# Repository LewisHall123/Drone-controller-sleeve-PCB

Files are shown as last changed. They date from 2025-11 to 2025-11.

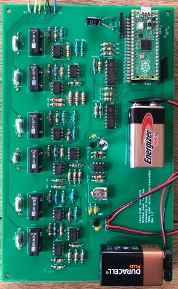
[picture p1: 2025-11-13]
TENG_input_PCB.jpg

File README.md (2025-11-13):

# Drone-controller-sleeve-PCB
A circuit designed to send commands to a drone that it controls. The inputs to the circuit that determine the commands come from six separate tribo-electric nanogenerators (TENG). The materials used for the TENG were aluminium foil and fluorinated ethylene propylene (FEP). The aluminium foil was arranged as six squares that sat on a sleeve that was secured to the users forearm. The aluminium squares were connected to electrodes that were inputs to the circuit. A glove was used with FEP material on the fingertips, and so when the user touched the aluminium squares on the sleeve, a voltage was created in the aluminium squares.
The six aluminium squares were controlls that were responsible for increasing or decreasing the values of roll, pitch, and yaw of the drone.
A Raspberry Pi Pico was used to determine the exact messages that could be sent to the HC-12 transceiver that would transmitt the commands to the drone.

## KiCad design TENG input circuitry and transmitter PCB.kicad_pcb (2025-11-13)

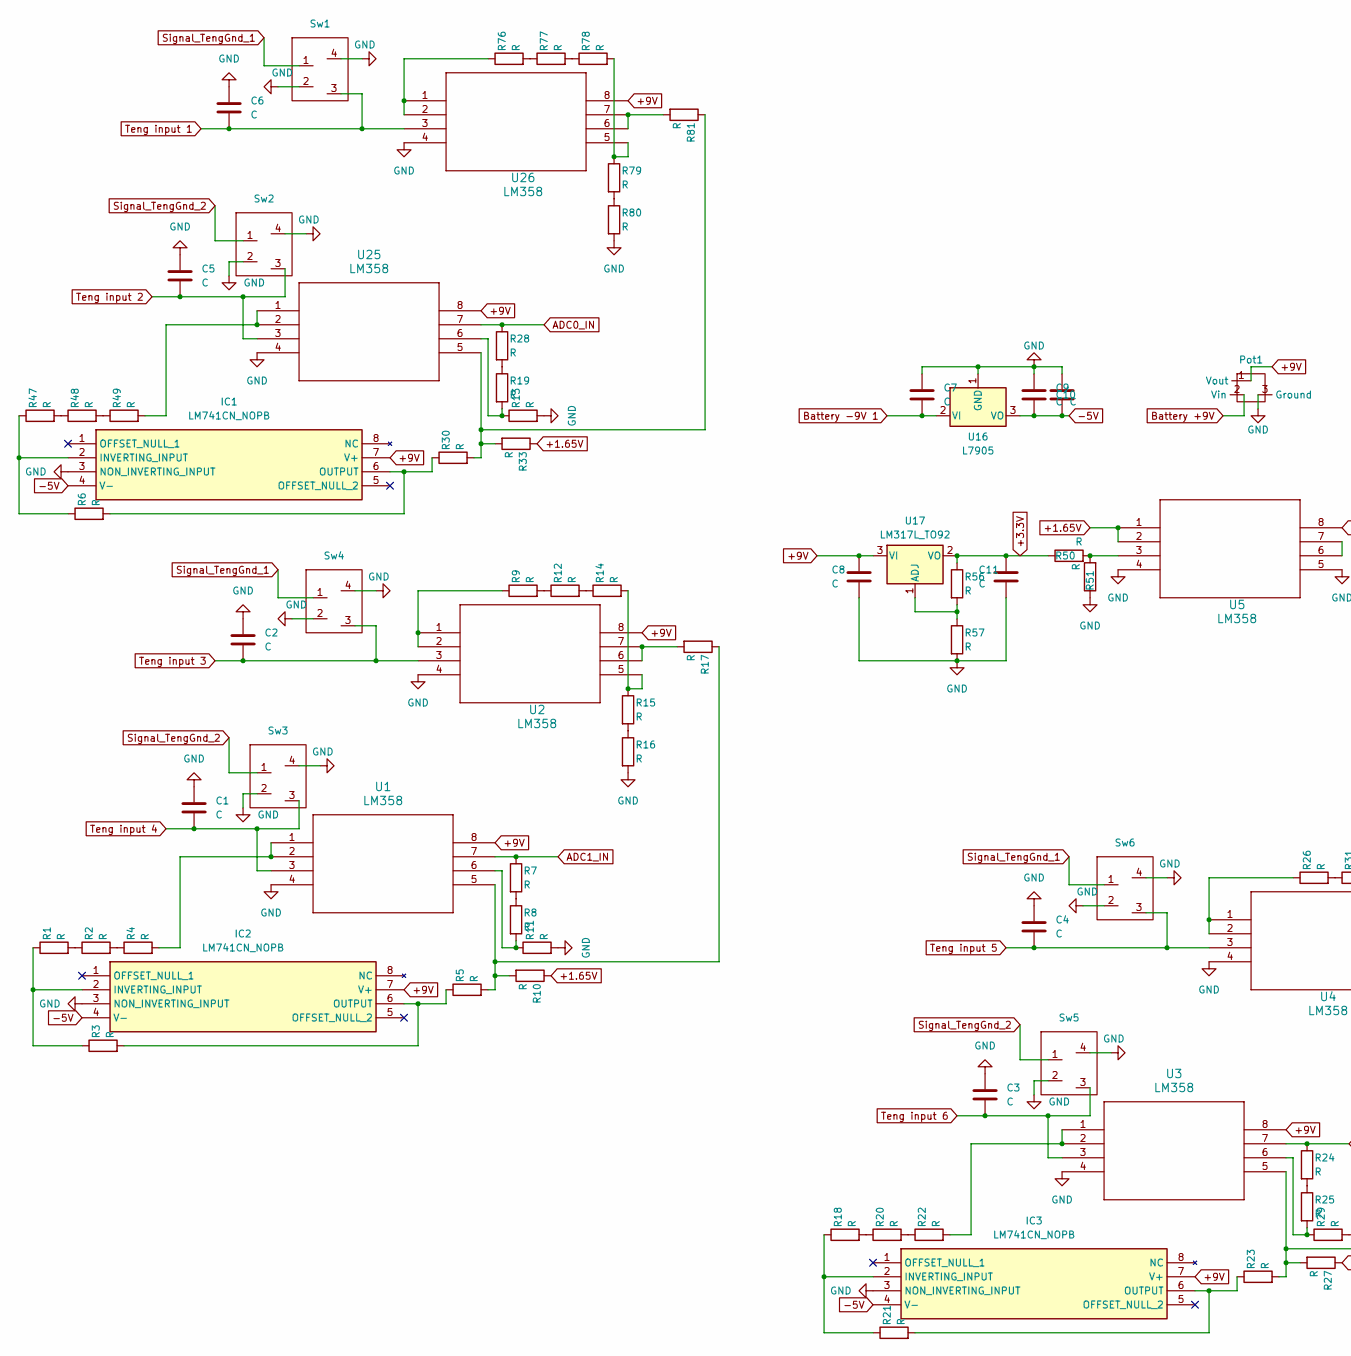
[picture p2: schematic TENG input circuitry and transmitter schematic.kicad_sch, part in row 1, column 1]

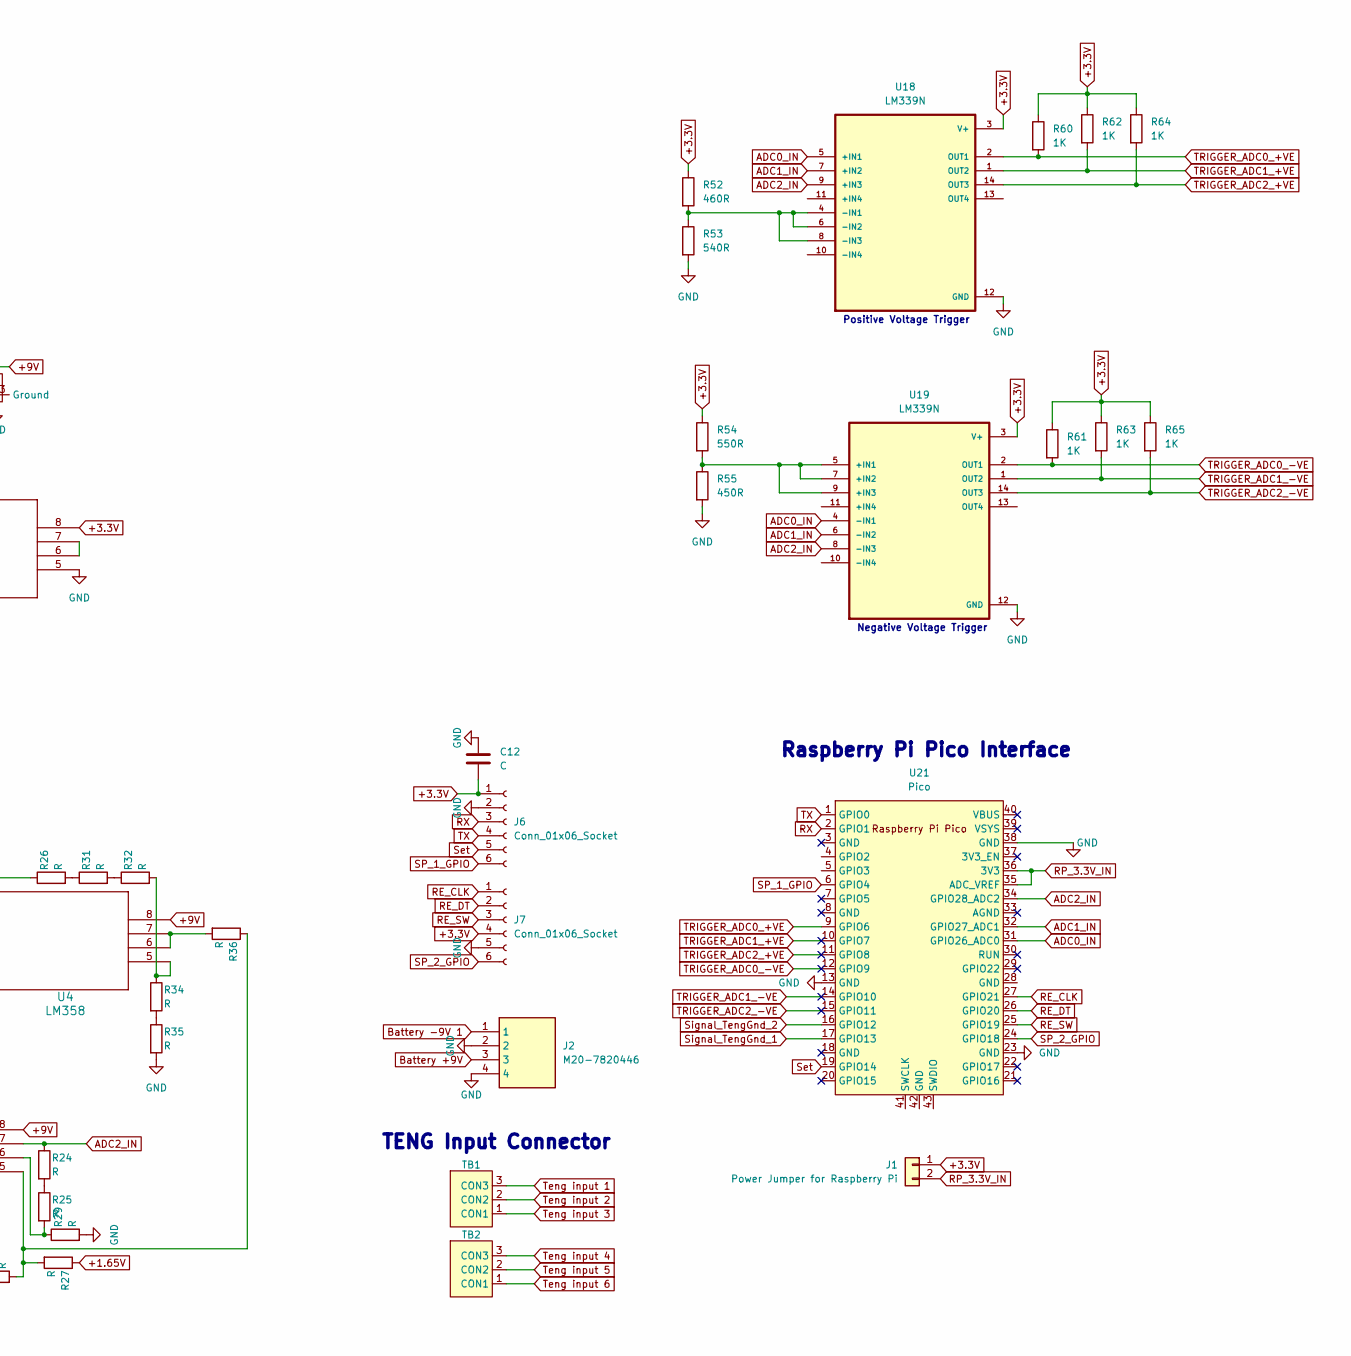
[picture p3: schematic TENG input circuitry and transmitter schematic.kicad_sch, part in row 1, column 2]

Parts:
C1, C2, C3, C4, C5, C6: C; CP_Axial_L10.0mm_D6.0mm_P15.00mm_Horizontal
C7, C9, C10, C11, C12: C; C_Axial_L3.8mm_D2.6mm_P7.50mm_Horizontal
C8: C; CP_Radial_D8.0mm_P5.00mm
IC1, IC2, IC3: LM741CN_NOPB; DIP794W53P254L959H508Q8N; Mouser Part Number 926-LM741CN/NOPB
J1: Power Jumper for Raspberry Pi; PinHeader_1x02_P2.54mm_Vertical
J2: M20-7820446; RHDR4W70P0X254_1X4_1056X250X865P; Mouser Part Number 855-M20-7820446
J6, J7: Conn_01x06_Socket; PinSocket_1x06_P2.54mm_Vertical
Pot1: 3359V-A05
R1, R2, R3, R4, R5, R6, R7, R8, R9, R10, R11, R12, R13, R14, R15, R16, R17, R18, R19, R20, R21, R22, R23, R24, R25, R26, R27, R28, R29, R30, R31, R32, R33, R34, R35, R36, R47, R48, R49, R50, R51, R56, R57, R76, R77, R78, R79, R80, R81: R; R_Axial_DIN0207_L6.3mm_D2.5mm_P10.16mm_Horizontal
R52: 460R; R_Axial_DIN0207_L6.3mm_D2.5mm_P10.16mm_Horizontal
R53: 540R; R_Axial_DIN0207_L6.3mm_D2.5mm_P10.16mm_Horizontal
R54: 550R; R_Axial_DIN0207_L6.3mm_D2.5mm_P10.16mm_Horizontal
R55: 450R; R_Axial_DIN0207_L6.3mm_D2.5mm_P10.16mm_Horizontal
R60, R61, R62, R63, R64, R65: 1K; R_Axial_DIN0207_L6.3mm_D2.5mm_P10.16mm_Horizontal
Sw1, Sw2, Sw3, Sw4, Sw5, Sw6: RS 291-9675
TB1, TB2: CTB30513BK
U1, U2, U3, U4, U5, U25, U26: LM358; DIP8_300
U16: L7905; LM336BLPE325
U17: LM317L_TO92; LM336BLPE325
U18, U19: LM339N; LM339
U21: Pico; New Pico

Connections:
+1.65V: R10.1, R27.1, R33.1, U5.1, U5.2
+3.3V: C11.1, C12.2, J1.1, J6.1, J7.4, R50.1, R52.1, R54.1, R56.1, R60.1, R61.1, R62.1, R63.1, R64.1, R65.1, U5.8, U17.2 (VO), U18.3 (V+), U19.3 (V+)
+9V: C8.1, IC1.7 (V+), IC2.7 (V+), IC3.7 (V+), Pot1.1 (Vout), U1.8, U2.8, U3.8, U4.8, U17.3 (VI), U25.8, U26.8
-5V: C9.2, C10.2, IC1.4 (V-), IC2.4 (V-), IC3.4 (V-), U16.3 (VO)
ADC0_IN: R28.1, U18.5 (+IN1), U19.4 (-IN1), U21.31 (GPIO26_ADC0), U25.7
ADC1_IN: R7.1, U1.7, U18.7 (+IN2), U19.6 (-IN2), U21.32 (GPIO27_ADC1)
ADC2_IN: R24.1, U3.7, U18.9 (+IN3), U19.8 (-IN3), U21.34 (GPIO28_ADC2)
Battery +9V: J2.3, Pot1.2 (Vin)
Battery -9V 1: C7.2, J2.1, U16.2 (VI)
GND: C1.1, C2.1, C3.1, C4.1, C5.1, C6.1, C7.1, C8.2, C9.1, C10.1, C11.2, C12.1, IC1.3 (NON_INVERTING_INPUT), IC2.3 (NON_INVERTING_INPUT), IC3.3 (NON_INVERTING_INPUT), J2.2, J2.4, J6.2, J7.5, Pot1.3 (Ground), R11.2, R13.2, R16.2, R29.2, R35.2, R51.1, R53.2, R55.2, R57.2, R80.2, Sw1.2, Sw1.4, Sw2.2, Sw2.4, Sw3.2, Sw3.4, Sw4.2, Sw4.4, Sw5.2, Sw5.4, Sw6.2, Sw6.4, U1.4, U2.4, U3.4, U4.4, U5.4, U5.5, U16.1 (GND), U18.12 (GND), U19.12 (GND), U21.13 (GND), U21.23 (GND), U21.38 (GND), U25.4, U26.4
unnamed: IC1.2 (INVERTING_INPUT), R6.1, R47.1
unnamed: IC1.6 (OUTPUT), R6.2, R30.1
unnamed: IC2.2 (INVERTING_INPUT), R1.1, R3.1
unnamed: IC2.6 (OUTPUT), R3.2, R5.1
unnamed: IC3.2 (INVERTING_INPUT), R18.1, R21.1
unnamed: IC3.6 (OUTPUT), R21.2, R23.1
unnamed: R1.2, R2.1
unnamed: R2.2, R4.1
unnamed: R4.2, U1.1, U1.2
unnamed: R7.2, R8.1
unnamed: R9.1, U2.1, U2.2
unnamed: R5.2, R10.2, R17.1, U1.5
unnamed: R8.2, R11.1, U1.6
unnamed: R9.2, R12.1
unnamed: R12.2, R14.1
unnamed: R13.1, R19.2, U25.6
unnamed: R14.2, R15.1, U2.5
unnamed: R15.2, R16.1
unnamed: R17.2, U2.6, U2.7
unnamed: R18.2, R20.1
unnamed: R19.1, R28.2
unnamed: R20.2, R22.1
unnamed: R22.2, U3.1, U3.2
unnamed: R23.2, R27.2, R36.1, U3.5
unnamed: R24.2, R25.1
unnamed: R25.2, R29.1, U3.6
unnamed: R26.1, U4.1, U4.2
unnamed: R26.2, R31.1
unnamed: R30.2, R33.2, R81.1, U25.5
unnamed: R31.2, R32.1
unnamed: R32.2, R34.1, U4.5
unnamed: R34.2, R35.1
unnamed: R36.2, U4.6, U4.7
unnamed: R47.2, R48.1
unnamed: R48.2, R49.1
unnamed: R49.2, U25.1, U25.2
unnamed: R50.2, R51.2, U5.3
unnamed: R76.1, U26.1, U26.2
unnamed: R76.2, R77.1
unnamed: R77.2, R78.1
unnamed: R78.2, R79.1, U26.5
unnamed: R79.2, R80.1
unnamed: R81.2, U26.6, U26.7
unnamed: U5.6, U5.7
unnamed: R56.2, R57.1, U17.1 (ADJ)
unnamed: R52.2, R53.1, U18.4 (-IN1), U18.6 (-IN2), U18.8 (-IN3)
unnamed: R54.2, R55.1, U19.5 (+IN1), U19.7 (+IN2), U19.9 (+IN3)
RE_CLK: J7.1, U21.27 (GPIO21)
RE_DT: J7.2, U21.26 (GPIO20)
RE_SW: J7.3, U21.25 (GPIO19)
RP_3.3V_IN: J1.2, U21.35 (ADC_VREF), U21.36 (3V3)
RX: J6.3, U21.2 (GPIO1)
SP_1_GPIO: J6.6, U21.6 (GPIO4)
SP_2_GPIO: J7.6, U21.24 (GPIO18)
Set: J6.5, U21.19 (GPIO14)
Signal_TengGnd_1: Sw1.1, Sw4.1, Sw6.1, U21.17 (GPIO13)
Signal_TengGnd_2: Sw2.1, Sw3.1, Sw5.1, U21.16 (GPIO12)
TRIGGER_ADC0_+VE: R60.2, U18.2 (OUT1), U21.9 (GPIO6)
TRIGGER_ADC0_-VE: R61.2, U19.2 (OUT1), U21.12 (GPIO9)
TRIGGER_ADC1_+VE: R62.2, U18.1 (OUT2), U21.10 (GPIO7)
TRIGGER_ADC1_-VE: R63.2, U19.1 (OUT2), U21.14 (GPIO10)
TRIGGER_ADC2_+VE: R64.2, U18.14 (OUT3), U21.11 (GPIO8)
TRIGGER_ADC2_-VE: R65.2, U19.14 (OUT3), U21.15 (GPIO11)
TX: J6.4, U21.1 (GPIO0)
Teng input 1: C6.2, Sw1.3, TB1.3 (CON3), U26.3
Teng input 2: C5.2, Sw2.3, TB1.2 (CON2), U25.3
Teng input 3: C2.2, Sw4.3, TB1.1 (CON1), U2.3
Teng input 4: C1.2, Sw3.3, TB2.3 (CON3), U1.3
Teng input 5: C4.2, Sw6.3, TB2.2 (CON2), U4.3
Teng input 6: C3.2, Sw5.3, TB2.1 (CON1), U3.3

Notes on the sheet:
Raspberry Pi Pico Interface
Negative Voltage Trigger
Positive Voltage Trigger
TENG Input Connector

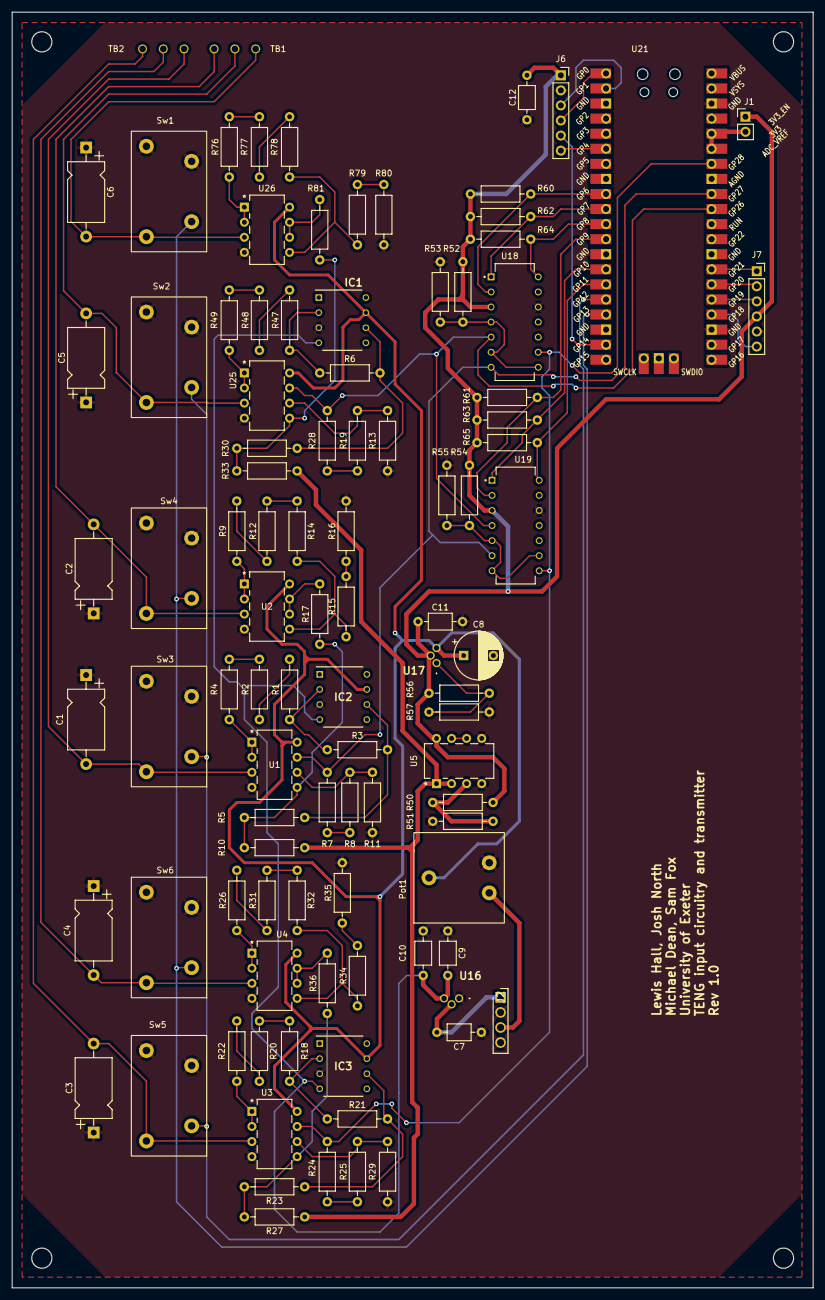
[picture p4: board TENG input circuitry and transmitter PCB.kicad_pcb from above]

Board: 2 copper layers, 135.0 x 215.0 mm, 99 parts (0 on the bottom side), 80 nets.

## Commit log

2025-11-13 Upload of PCD layout, schematic, and Gerber files
    [TENG input circuitry and transmitter PCB.kicad_pcb, TENG input circuitry and transmitter schematic.kicad_sch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]
2025-11-13 Enhance README with detailed project description
    Expanded the project description to include details about the materials used, the setup, and the components involved in the circuit.
2025-11-13 Picture of the finished PCB
